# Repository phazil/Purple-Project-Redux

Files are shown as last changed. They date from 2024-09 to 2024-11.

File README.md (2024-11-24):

# Purple Project Redux

A recreation of @TheTrain24's Purple Project seen here:
[Reference Posts](https://github.com/phazil/Purple-Project-Redux/blob/main/Docs/Inspiration%20Posts.md)

This started out as a post graduation project (someone in biology hire me pls) to explore deeper into the hobbies I was already interested in. Did all of the CAD/KiCAD work myself, and also because I missed out on the originals Train posted. Lots was learned here, and documenting it all isn't as fun as making it but I guess it's necessary lol. 

This is my attempt to recreate Train's version, however there are differences. There is no custom wiring terminal pcb, it's not double stacked FR4 for both front/back panel, and there's no usage of low profile OSBMXs. I used a right angle header soldered onto a Basic Breakout Board running GP2040-CE along with a 20-pin wiring harness. There is some soldering involved in this to get the menu panel working however it is sequential and there's only 1 ground line needed. The single panel do not flex at all with the increase inside area of the 3D prints. you would have to try to push down really hard on the center of the panels to even see any sort of flex. Any low profile buttons that fit within a 20mm tall enclosure should work too.

As regards for making and selling, I do not think this is the most efficient way to go about it. The original project I am pretty sure was scrapped due to how expensive FR4 panels end up being. Using laser cut acrylic is probably more efficient for anything of the sorts. Total cost for making 5 of these is about $750 with the materials I chose, so around $160 each is close to breaking even. This does not at all account for the time needed to print parts or build this.

If you need any help or are even thinking about making this please contact me on Discord! I'd be willing to help. @phazil

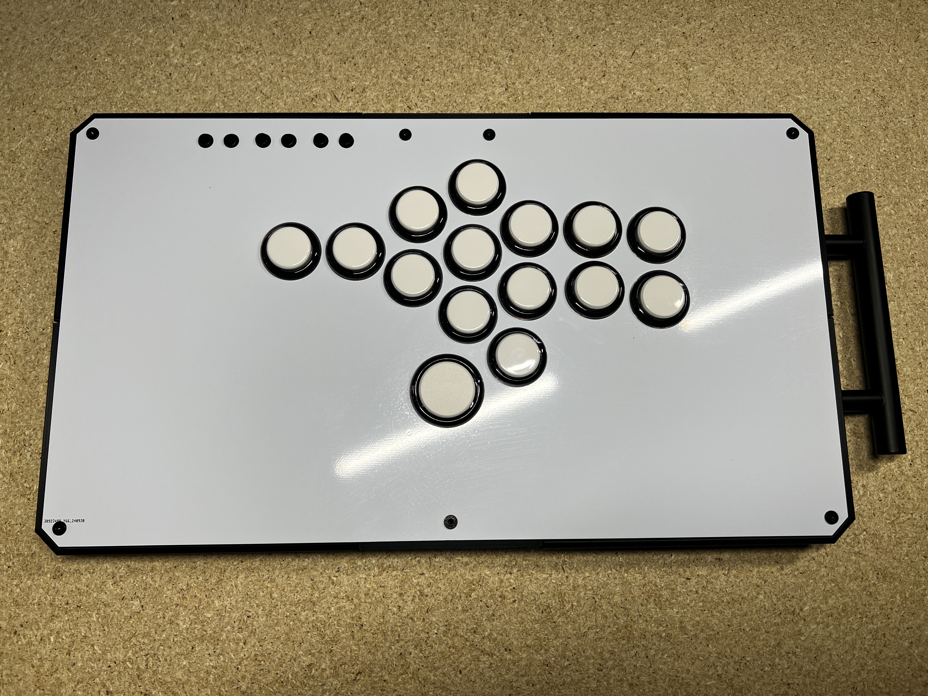
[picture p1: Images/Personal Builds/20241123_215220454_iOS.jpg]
Showcase Test

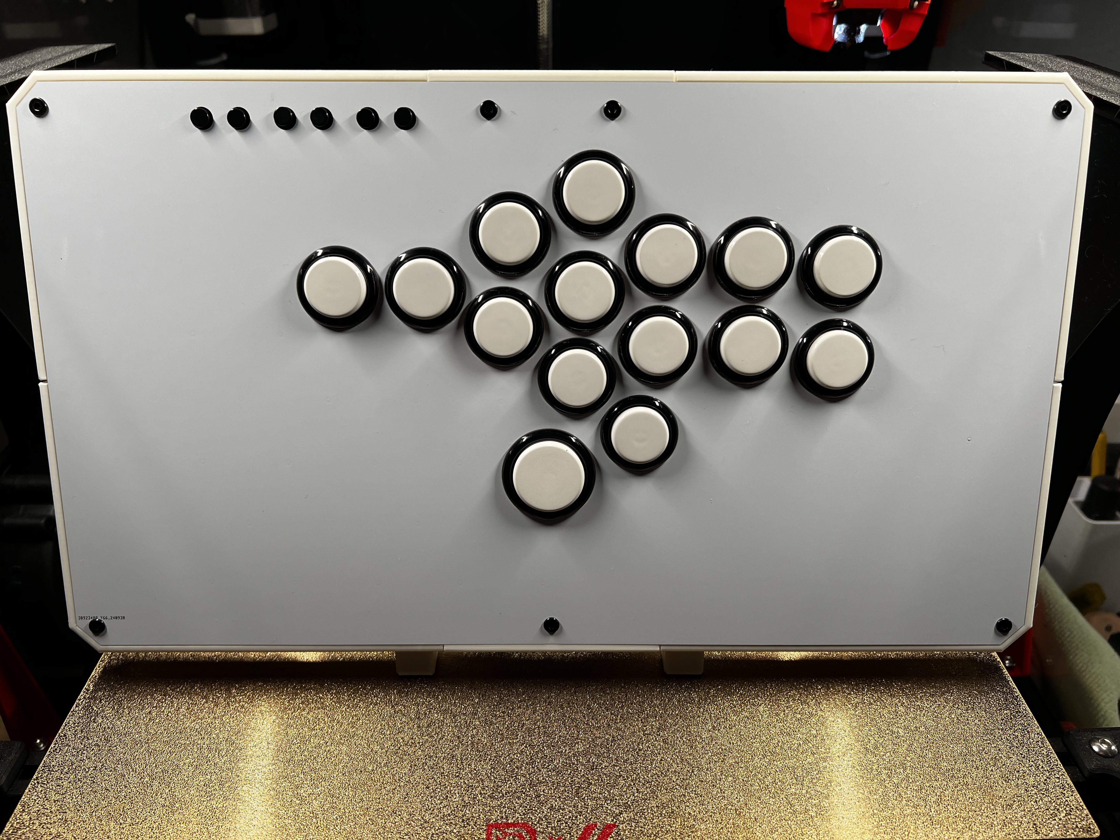
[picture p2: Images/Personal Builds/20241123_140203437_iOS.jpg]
Showcase Test 2


## Repository Directory:
* [Full Readme](https://github.com/phazil/Purple-Project-Redux/blob/main/README.md)
	* [Reference Posts](https://github.com/phazil/Purple-Project-Redux/blob/main/Docs/Inspiration%20Posts.md)
	* [Bill of Materials](https://github.com/phazil/Purple-Project-Redux/blob/main/Docs/Bill%20of%20Materials.md)
   	* [Ordering Panels and PCBs](https://github.com/phazil/Purple-Project-Redux/blob/main/Docs/Ordering%20Guide.md)
 	* [Printing Parts](https://github.com/phazil/Purple-Project-Redux/blob/main/Docs/Printing%20Parts.md)
	* [Rough Assembly Guide](https://github.com/phazil/Purple-Project-Redux/blob/main/Docs/Assembly%20Guide.md)
 	* [Editting Parts](https://github.com/phazil/Purple-Project-Redux/blob/main/Docs/Editting%20Parts.md)

## Features, Details, and To-Dos

### 3 Variations:
- Purple Project Redux: 35.56cm x 20.32cm x 2.32cm (14" x 8" x 0.9")
- **UNTESTED** Acrylic Layer Version: 35.56cm x 20.32cm x 2.47cm (14" x 8" x 0.97")
- Right side carrying handle modifcation available for both (Adds about 1.25" to total length)

### Features:
- Daigo-ish Layout
- Stickless+
- Bottom Rubber Pads
	- Mirrored for both sides
- Right side carrying handle
- PCB top/bottom plate (1.6mm)
- Possible Acrylic Top Plate (3.1mm total thickness, only screw ins work)
- Designed PCB Auxilliary Button Panel

Each designed part can fit in a 250x250x250 volume print bed
- 6 total pieces
	- Top Left
	- Top Right
	- Top Middle (Requires USB-C keystone jack panel mount)
	- Bottom Left
	- Bottom Middle
	- Bottom Right
- Printed in [Voron Spec](https://docs.vorondesign.com/sourcing.html#print-settings) hopefully

### To Do's:
- [x] BOM Page written
- [x] Ordering Page written
- [x] Printing Parts written
- [x] Rough Assembly Guide written
- [x] Editting Parts written
- [ ] Bottom Rubber/Foam pad DXFs

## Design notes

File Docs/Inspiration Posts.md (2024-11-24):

## Repository Directory:
* [Full Readme](https://github.com/phazil/Purple-Project-Redux/blob/main/README.md)
	* [Reference Posts](https://github.com/phazil/Purple-Project-Redux/blob/main/Docs/Inspiration%20Posts.md)
	* [Bill of Materials](https://github.com/phazil/Purple-Project-Redux/blob/main/Docs/Bill%20of%20Materials.md)
   	* [Ordering Panels and PCBs](https://github.com/phazil/Purple-Project-Redux/blob/main/Docs/Ordering%20Guide.md)
 	* [Printing Parts](https://github.com/phazil/Purple-Project-Redux/blob/main/Docs/Printing%20Parts.md)
	* [Rough Assembly Guide](https://github.com/phazil/Purple-Project-Redux/blob/main/Docs/Assembly%20Guide.md)
 	* [Editting Parts](https://github.com/phazil/Purple-Project-Redux/blob/main/Docs/Editting%20Parts.md)

## These are the original posts that I used as a reference for this project

[Detailed Pictures Stored Here](https://github.com/phazil/Purple-Project-Redux/tree/main/Images/OpenStickCommunity%20Posts/2)

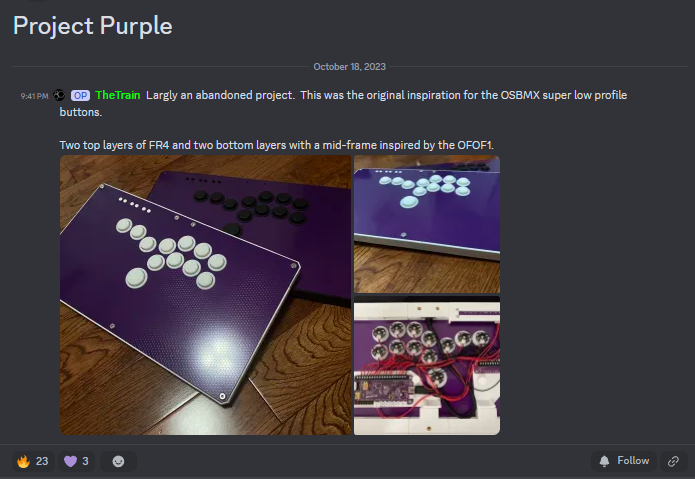
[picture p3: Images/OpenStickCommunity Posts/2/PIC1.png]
Reference Post 1


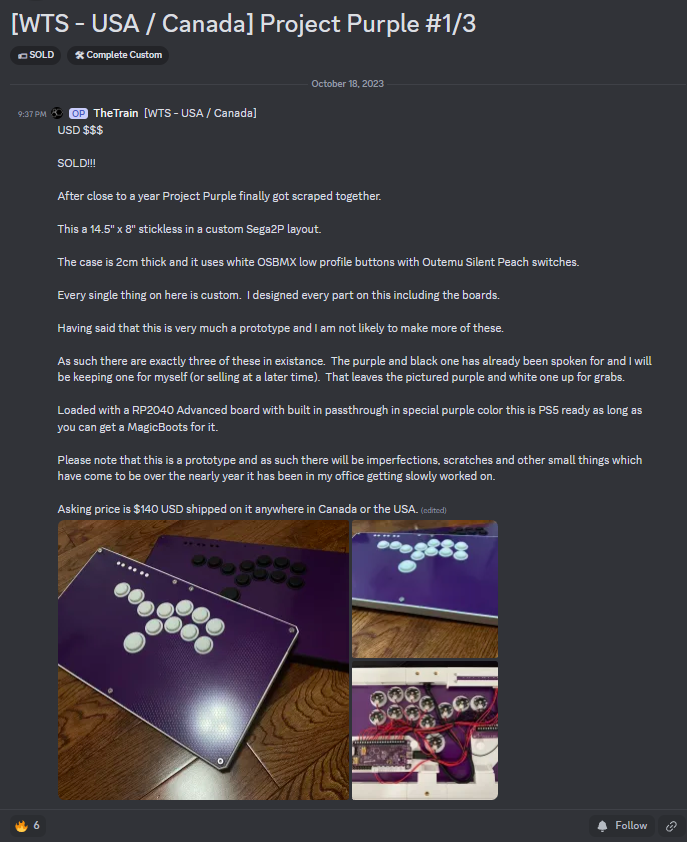
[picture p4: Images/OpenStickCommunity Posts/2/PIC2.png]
Reference Post 2


[Detailed Pictures of This Post Here](https://github.com/phazil/Purple-Project-Redux/tree/main/Images/OpenStickCommunity%20Posts/2)

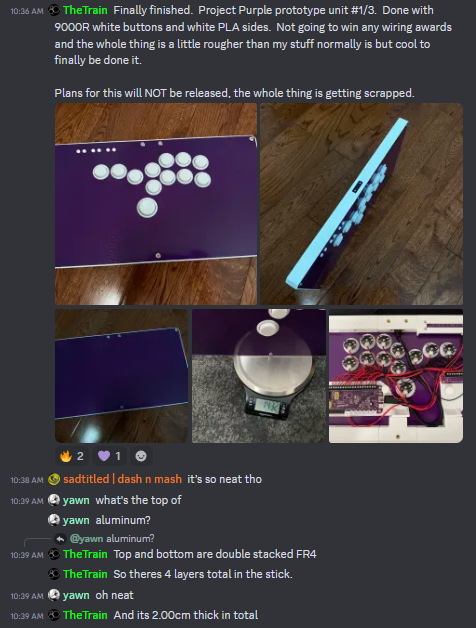
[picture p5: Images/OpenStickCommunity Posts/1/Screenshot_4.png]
Reference Post 3


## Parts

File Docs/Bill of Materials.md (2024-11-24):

## Repository Directory:
* [Full Readme](https://github.com/phazil/Purple-Project-Redux/blob/main/README.md)
	* [Reference Posts](https://github.com/phazil/Purple-Project-Redux/blob/main/Docs/Inspiration%20Posts.md)
	* [Bill of Materials](https://github.com/phazil/Purple-Project-Redux/blob/main/Docs/Bill%20of%20Materials.md)
   	* [Ordering Panels and PCBs](https://github.com/phazil/Purple-Project-Redux/blob/main/Docs/Ordering%20Guide.md)
 	* [Printing Parts](https://github.com/phazil/Purple-Project-Redux/blob/main/Docs/Printing%20Parts.md)
	* [Rough Assembly Guide](https://github.com/phazil/Purple-Project-Redux/blob/main/Docs/Assembly%20Guide.md)
 	* [Editting Parts](https://github.com/phazil/Purple-Project-Redux/blob/main/Docs/Editting%20Parts.md)

## Bill of Materials:

There is a mix of Aliexpress links and Amazon links used here. There is no affiliate/metadata tracking on these links.

- [Overture PLA works w/ Bambulabs AMS](https://www.amazon.com/gp/product/B082W64GTZ)
- [Voron Spec Heatset Inserts M3x5x4](https://www.amazon.com/gp/product/B0CDH36ZMX)
- Three different version of USB-C Keystone Jack inserts, pick whatever works
  - [Black USB-C Keystone Jack](https://www.amazon.com/gp/product/B0CP753PCP)
  - [White USB-C Keystone Jack](https://www.amazon.com/gp/product/B078495TVK)
  - [Use this one if not using Stickless+ Panels](https://www.amazon.com/gp/product/B08GSQ13C8)
- [Handle Used + Screws](https://www.amazon.com/gp/product/B085ZRBTPY)
- M3x4 or M3x6
  - [Black Screws](https://www.aliexpress.us/item/3256804883804669.html)
  - [Silver Screws](https://www.aliexpress.us/item/3256802038301655.html)
- [Low Profile SiTongs](https://www.aliexpress.us/item/3256807199829923.html)
- [6x6x7/8 A56 Momentary Pushbutton](https://www.ebay.co.uk/itm/233216080460) If you didn't get the Menu Panel assembled with push buttons.
- [Menu Panel Caps](https://www.aliexpress.us/item/3256804815046475.html)

- Some kind of Advanced/Basic Breakout Boards running GP2040-CE
  - [Right Angle Header if you're interested in using a wiring harness in the build](https://www.amazon.com/gp/product/B00W8TSWXS)
 
## Total Counts:

- Button Panel
  - Optional Acrylic Layer
- Back Panel
- 20 M3x4/6 screws
  - 14 screws for the panels
  - 6 for holding down PCBs inside
- 14 M3x5x4 Heatset Inserts
- 1 USB-C Keystone Jack
- 1 Advanced/Basic Breakout Board
- 1 Menu Panel PCB
- 6 6x6x7/8 Momentary Push Buttons
- 6 A56 Button Caps
- Low Profile Buttons (SiTongs/Monkey BuTTs etc.)
  - 24mms Buttons
    - 14 for Stickless+
    - 13 for Daigo-ish
    - 11 for Standard Leverless
  - 1 30mm

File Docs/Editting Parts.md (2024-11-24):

## Repository Directory:
* [Full Readme](https://github.com/phazil/Purple-Project-Redux/blob/main/README.md)
	* [Reference Posts](https://github.com/phazil/Purple-Project-Redux/blob/main/Docs/Inspiration%20Posts.md)
	* [Bill of Materials](https://github.com/phazil/Purple-Project-Redux/blob/main/Docs/Bill%20of%20Materials.md)
   	* [Ordering Panels and PCBs](https://github.com/phazil/Purple-Project-Redux/blob/main/Docs/Ordering%20Guide.md)
 	* [Printing Parts](https://github.com/phazil/Purple-Project-Redux/blob/main/Docs/Printing%20Parts.md)
	* [Rough Assembly Guide](https://github.com/phazil/Purple-Project-Redux/blob/main/Docs/Assembly%20Guide.md)
 	* [Editting Parts](https://github.com/phazil/Purple-Project-Redux/blob/main/Docs/Editting%20Parts.md)

## Editting Parts

Within the [Source Files Folder](https://github.com/phazil/Purple-Project-Redux/tree/main/Source%20Files) everything is accessible and changeable.

DXFs, STEPs, and PCB files are all available.

They were created in Fusion 360 and KiCAD 8.0.

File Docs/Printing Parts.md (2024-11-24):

## Repository Directory:
* [Full Readme](https://github.com/phazil/Purple-Project-Redux/blob/main/README.md)
	* [Reference Posts](https://github.com/phazil/Purple-Project-Redux/blob/main/Docs/Inspiration%20Posts.md)
	* [Bill of Materials](https://github.com/phazil/Purple-Project-Redux/blob/main/Docs/Bill%20of%20Materials.md)
   	* [Ordering Panels and PCBs](https://github.com/phazil/Purple-Project-Redux/blob/main/Docs/Ordering%20Guide.md)
 	* [Printing Parts](https://github.com/phazil/Purple-Project-Redux/blob/main/Docs/Printing%20Parts.md)
	* [Rough Assembly Guide](https://github.com/phazil/Purple-Project-Redux/blob/main/Docs/Assembly%20Guide.md)
 	* [Editting Parts](https://github.com/phazil/Purple-Project-Redux/blob/main/Docs/Editting%20Parts.md)

## Printing Parts:
The [STL folder](https://github.com/phazil/Purple-Project-Redux/tree/main/For%20Makers/STLs) is organized for you to print the base version then expand onto any variations you're interested in.

***The Stickless+ Version Panels has the USB-C Keystone Passthrough collide with the button housings, an alternative version is provided where the USB-C port is shifted over to avoid colliding if you're not interested in clipping the port down.***

Each designed part can fit in a **250x250x250 volume** print bed

Total print time is about **10 hours** and around **11 with supports**.

Total filament used is about **300 grams**. All parts were designed with PLA usage in mind, you would have to account for ABS/ASA shrinkage on your own if you're interested in that material. PETG is also useable too. PLA users please remember to take care of storing this controller in 90*F weather as it may warp in direct sunlight.

All parts are already orientated in printing position. The PCB piece can use **tree supports on the build plate only**. 
- 6 total pieces
	- Top Left
	- Top Right
	- Top Middle (Requires USB-C keystone jack panel mount)
	- Bottom Left
	- Bottom Middle
	- Bottom Right

These settings help give a rigid feeling when putting the build together. Although 3 walls/top layers will also work with a 20% infill density
- Printed in [Voron Spec](https://docs.vorondesign.com/sourcing.html#print-settings) hopefully
  - Layer height: 0.2mm
  - Extrusion width: 0.4mm, forced
  - Infill percentage: 40%
  - Infill type: grid, gyroid, honeycomb, triangle, or cubic
  - Wall count: 4
  - Solid top/bottom layers: 5
  - Supports: NONE

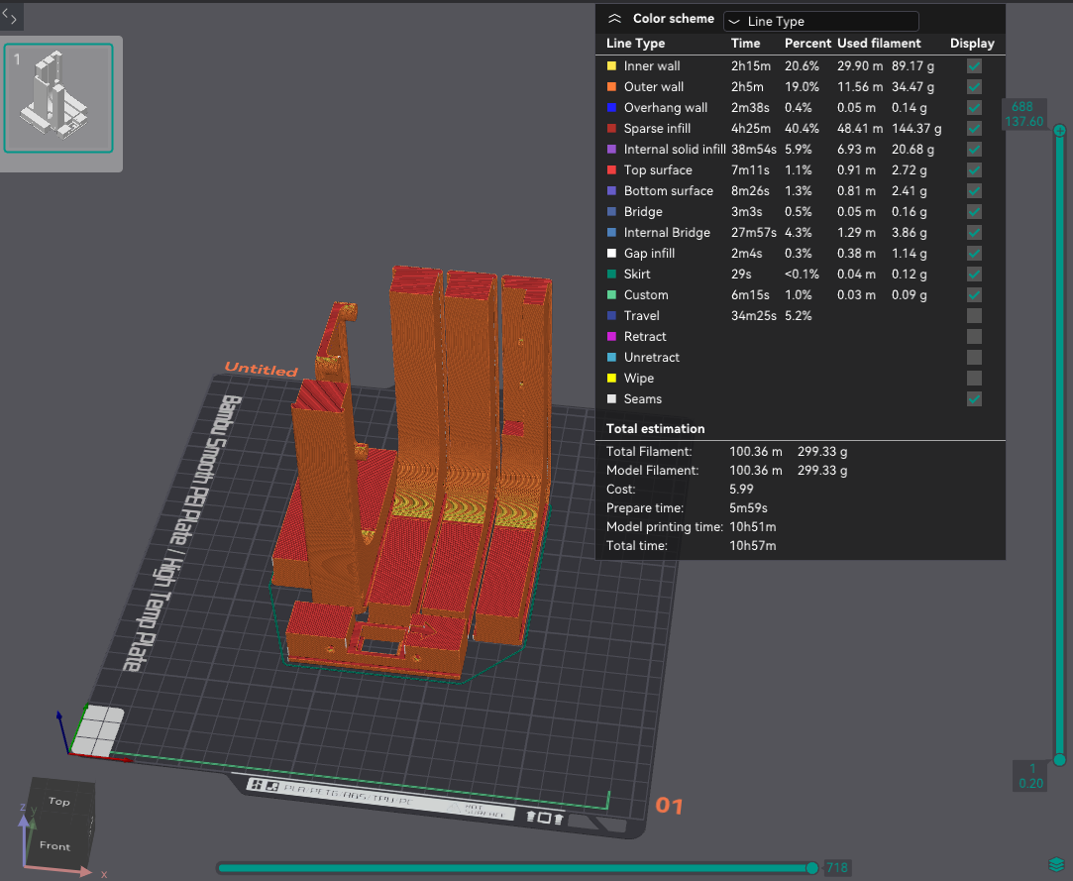
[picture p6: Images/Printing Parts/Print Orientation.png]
Print Orientation 1

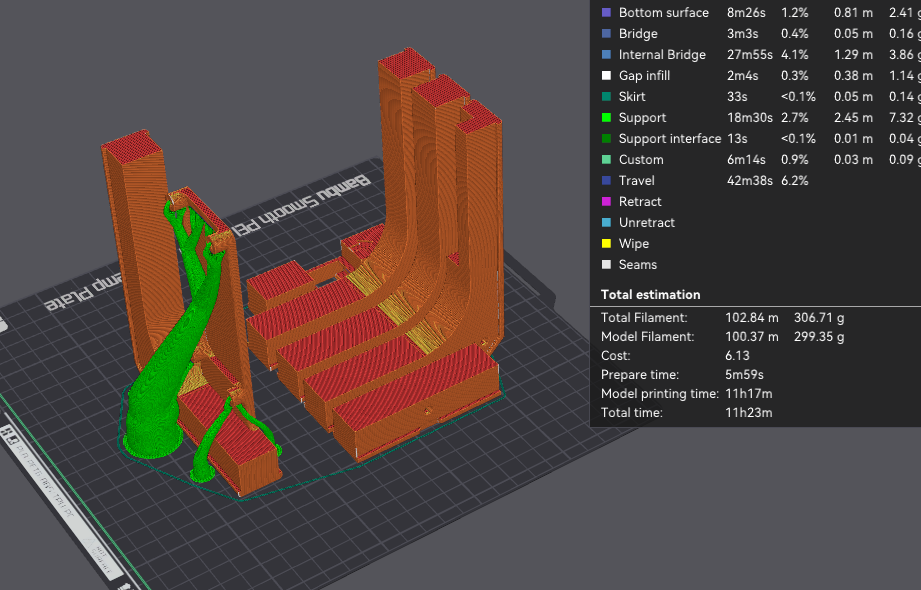
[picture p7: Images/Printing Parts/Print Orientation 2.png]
Print Orientation 2


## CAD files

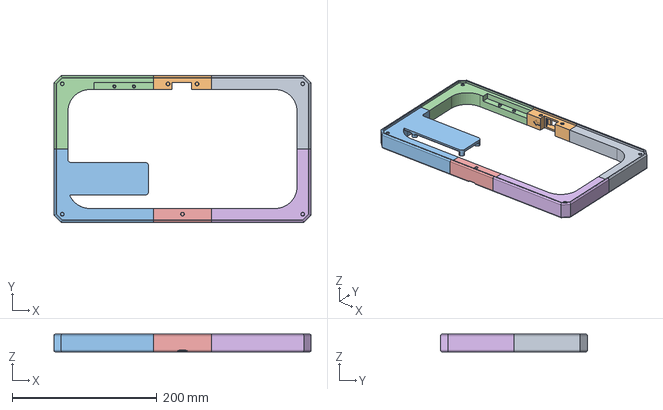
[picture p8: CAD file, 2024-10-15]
Source Files/STEP Files/Orignal + Acrylic/Full Body Acrylic.step
355.6 x 203.2 x 24.7 mm

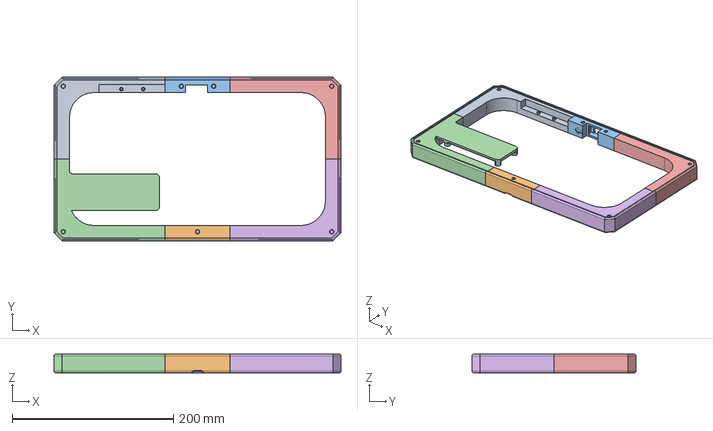
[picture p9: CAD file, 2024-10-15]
Source Files/STEP Files/Original/Full Body No Acrylic.step
355.6 x 203.2 x 23.2 mm

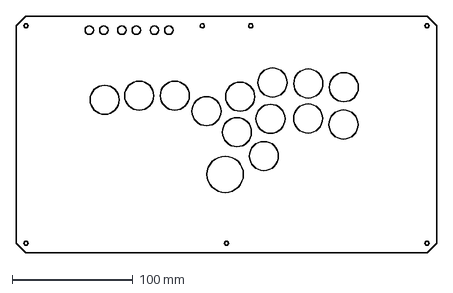
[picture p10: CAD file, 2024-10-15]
For Makers/Panel DXFs/Daigo-ish.dxf
348.6 x 196.2 mm

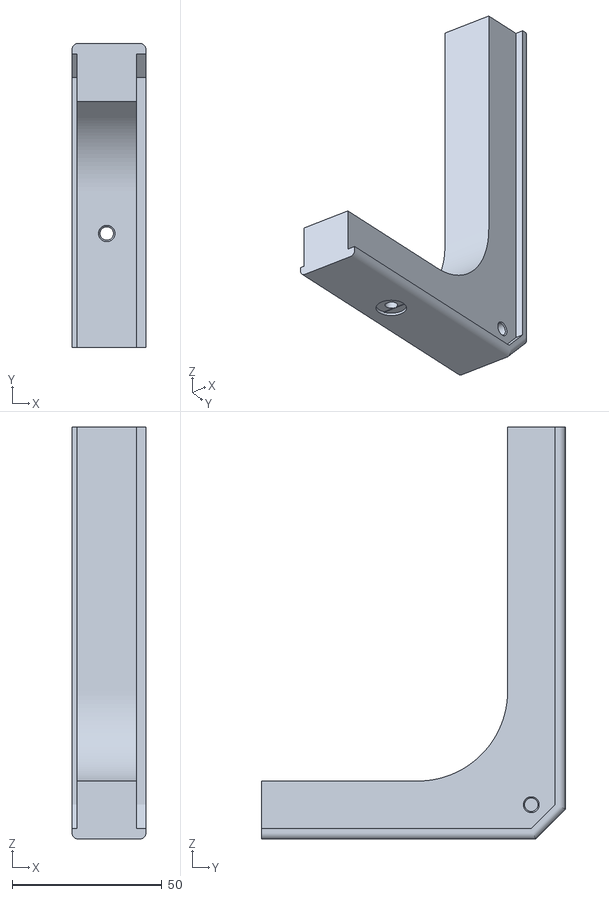
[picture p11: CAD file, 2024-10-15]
For Makers/STLs/Original + Acrylic/Right Side Handles/Top Right Acrylic Handle.stl
24.7 x 101.6 x 137.6

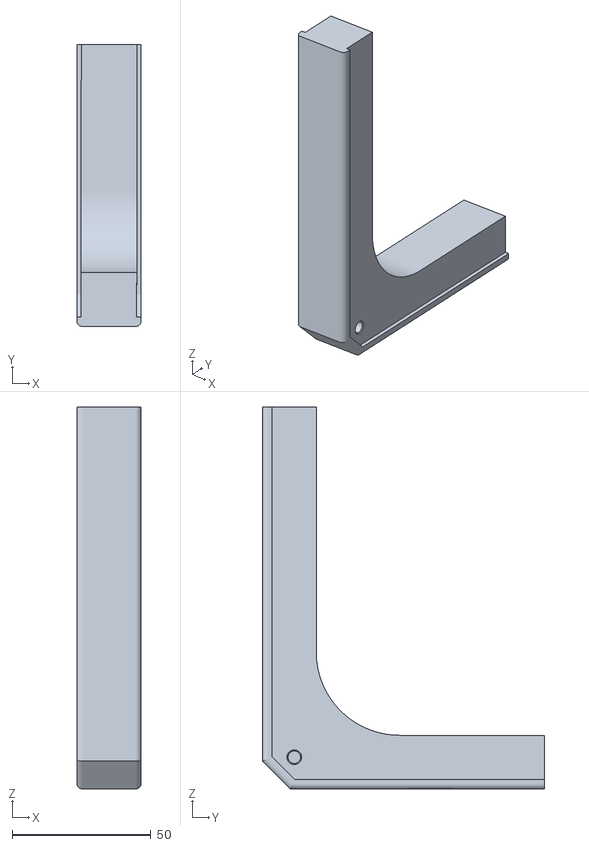
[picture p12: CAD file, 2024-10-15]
For Makers/STLs/Original/Bottom Right No Handle.stl
23.2 x 101.6 x 137.6

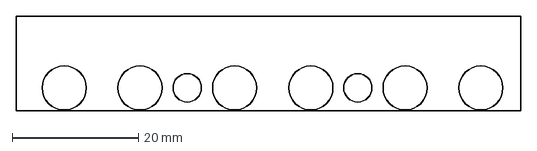
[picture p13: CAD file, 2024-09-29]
Source Files/KiCAD Files/MenuPanel/MenuPanelDXFforKiCAD.dxf
80.0 x 15.0 mm

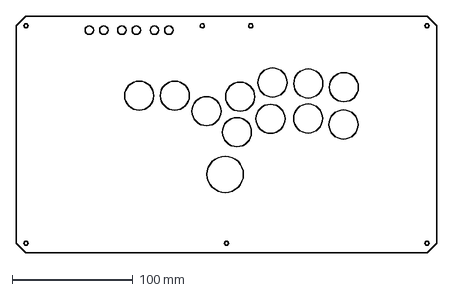
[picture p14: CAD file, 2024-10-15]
Source Files/Panel DXFs/Leverless.dxf
348.6 x 196.2 mm

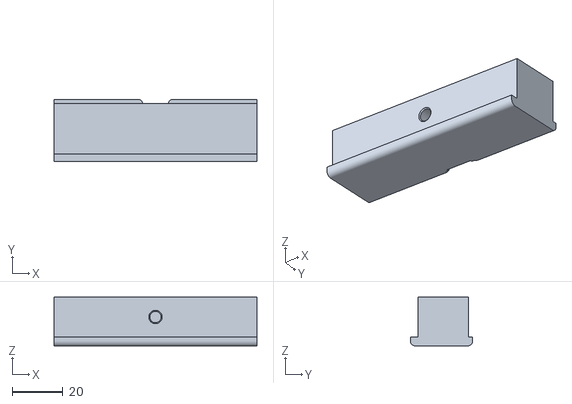
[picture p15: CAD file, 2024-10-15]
For Makers/STLs/Original + Acrylic/Bottom Middle Acrylic.stl
80.3 x 24.7 x 19.4

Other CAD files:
For Makers/STLs/Original + Acrylic/SticklessPLUS STLs/Top Right StickPLUS No Handle Acrylic.stl
For Makers/STLs/Original + Acrylic/Top Left Acrylic.stl
For Makers/STLs/Original/Right Side Handle STLs/Bottom Right Handle.stl
For Makers/STLs/Original/SticklessPLUS STLs/Top Right StickPLUS No Handle.stl
Source Files/STEP Files/Original/Right Side Handle/Bottom Right Handle.step
Source Files/STEP Files/Original/SticklessPLUS STEP/Top Right StickPLUS Handle.step
Source Files/STEP Files/Original/Top Right.step
Source Files/STEP Files/Orignal + Acrylic/Right Side Handle/Bottom Right Handle Acrylic.step
Source Files/STEP Files/Orignal + Acrylic/SticklessPLUS STEP/Top Right StickPLUS No Handle Acrylic.step
For Makers/Panel DXFs/Back Panel.dxf
For Makers/Panel DXFs/SticklessPLUS.dxf
For Makers/STLs/Original + Acrylic/Bottom Left Acrylic.stl
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

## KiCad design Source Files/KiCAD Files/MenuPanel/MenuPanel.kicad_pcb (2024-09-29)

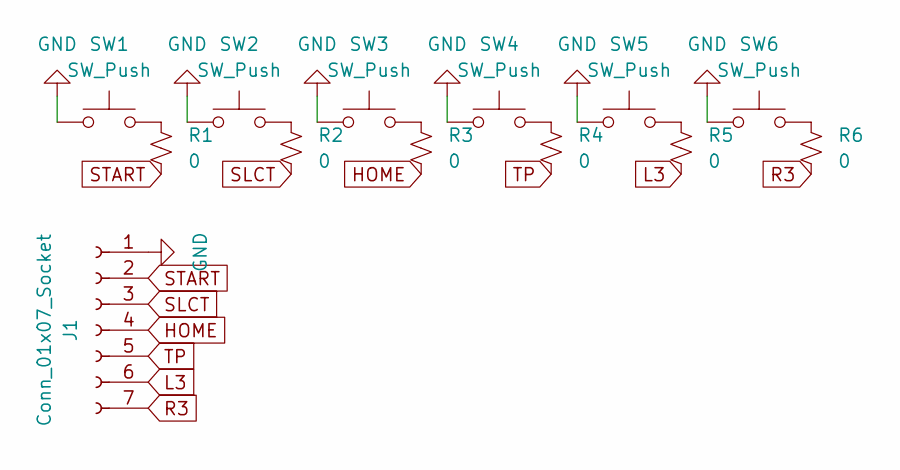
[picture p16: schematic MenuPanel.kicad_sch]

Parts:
J1: Conn_01x07_Socket; PinSocket_1x07_P2.54mm_Vertical
R1, R2, R3, R4, R5, R6: 0; R_0805_2012Metric_Pad1.20x1.40mm_HandSolder
SW1, SW2, SW3, SW4, SW5, SW6: SW_Push; SW_PUSH_6mm_H4.3mm

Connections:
GND: J1.1, SW1.1, SW2.1, SW3.1, SW4.1, SW5.1, SW6.1
HOME: J1.4, R3.2
L3: J1.6, R5.2
unnamed: R1.1, SW1.2
unnamed: R2.1, SW2.2
unnamed: R3.1, SW3.2
unnamed: R4.1, SW4.2
unnamed: R5.1, SW5.2
unnamed: R6.1, SW6.2
R3: J1.7, R6.2
SLCT: J1.3, R2.2
START: J1.2, R1.2
TP: J1.5, R4.2

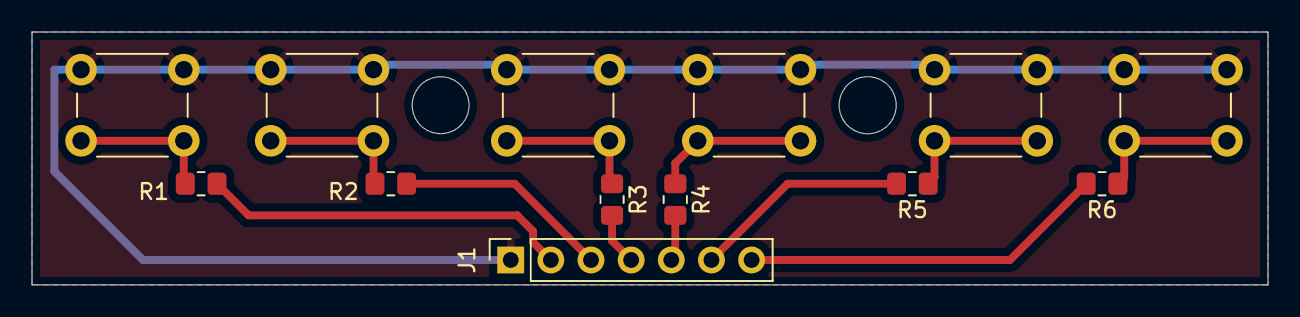
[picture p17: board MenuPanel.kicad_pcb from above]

Board: 2 copper layers, 78.2 x 16.0 mm, 13 parts (0 on the bottom side), 13 nets.

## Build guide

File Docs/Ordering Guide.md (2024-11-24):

## Repository Directory:
* [Full Readme](https://github.com/phazil/Purple-Project-Redux/blob/main/README.md)
	* [Reference Posts](https://github.com/phazil/Purple-Project-Redux/blob/main/Docs/Inspiration%20Posts.md)
	* [Bill of Materials](https://github.com/phazil/Purple-Project-Redux/blob/main/Docs/Bill%20of%20Materials.md)
   	* [Ordering Panels and PCBs](https://github.com/phazil/Purple-Project-Redux/blob/main/Docs/Ordering%20Guide.md)
 	* [Printing Parts](https://github.com/phazil/Purple-Project-Redux/blob/main/Docs/Printing%20Parts.md)
	* [Rough Assembly Guide](https://github.com/phazil/Purple-Project-Redux/blob/main/Docs/Assembly%20Guide.md)
 	* [Editting Parts](https://github.com/phazil/Purple-Project-Redux/blob/main/Docs/Editting%20Parts.md)

## Ordering Guide

I used JLCPCB for these. 1.6mm PCB thickness. Remove Order Number. Pick your panel color and silkscreen color. Obviously white silkscreen on black panels and black on white panels if you want it like that. The back panel is reversible too if you're not interested in the logos. Pick whatever surface finish is cheapest for you or whatever you favor.

JLC QC/QA might flag you asking if there's any grounding/metal on the panels. Just accept the risks and they should come out fine.

Within the [Panel Production Files](https://github.com/phazil/Purple-Project-Redux/tree/main/For%20Makers/Panel%20Production%20Files) you need to pick a front panel then add on the back panels.

As for the MenuPanel you will need assembly as I did include 0 ohm resistors just in case they were needed.

The Zip file included has the production files/BOM/designators/locations, you can choose to have JLCPCB install the momentary push buttons or you can do them yourself. 1.6mm and whatever color you want if that matters.

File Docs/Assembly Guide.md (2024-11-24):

## Repository Directory:
* [Full Readme](https://github.com/phazil/Purple-Project-Redux/blob/main/README.md)
	* [Reference Posts](https://github.com/phazil/Purple-Project-Redux/blob/main/Docs/Inspiration%20Posts.md)
	* [Bill of Materials](https://github.com/phazil/Purple-Project-Redux/blob/main/Docs/Bill%20of%20Materials.md)
   	* [Ordering Panels and PCBs](https://github.com/phazil/Purple-Project-Redux/blob/main/Docs/Ordering%20Guide.md)
 	* [Printing Parts](https://github.com/phazil/Purple-Project-Redux/blob/main/Docs/Printing%20Parts.md)
	* [Rough Assembly Guide](https://github.com/phazil/Purple-Project-Redux/blob/main/Docs/Assembly%20Guide.md)
 	* [Editting Parts](https://github.com/phazil/Purple-Project-Redux/blob/main/Docs/Editting%20Parts.md)

## Assembly Guide:

This is going to be really rough as it's a pretty simple build but there is an order I found to be pretty efficient. I am assuming you're pretty crafty/mechanically inclined to be able to wield a soldering iron especially if you're able to 3D print these parts.

## Build:

Heatset Inserts first
  > How even and straight you press them in is pretty important for how the panels sit.

Insert Buttons into front panel

Insert USB-C Keystone Jack into Top Middle piece, there is an arrow to orientate you to which way. It only goes in one way.

Screw 4 or 5 of the 6 pieces onto the front panel, you would have to hold off on the Top Left piece so you can handle the PCBs.

Screw in the Menu Panel PCB, should take 2 M3s directly into the 3D print

Screw in Main PCB (ABB or BBB) directly into the 3D print

Start wiring your action and movement buttons
  > Take your time with this as how neat you handle it saves you so much space

Solder your Menu Panel the square through hole is ground, and if you're using a wiring harness you can snip/strip then solder it into the hole. You can pick the order of what you want your buttons to be. I generally did Start/Select/Home/TP/L3/R3. From Left to Right after the ground.

OPTIONAL Solder your/plug in your extra face buttons if you're using Stickless+ or Daigo-ish layouts

After you're done wiring you can screw Top Left/Bottom Left onto the front panel only reason why we didn't do this earlier as it was easier to manipulate these pieces to access.

Close it up and you should be good, if you mess up there is a little indent on Bottom Middle to let you open it up again

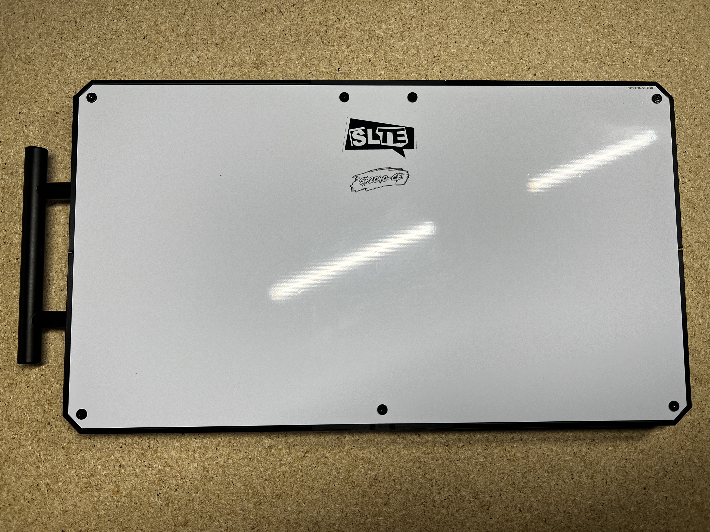
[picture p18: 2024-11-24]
Images/Personal Builds/20241123_215338252_iOS.jpg

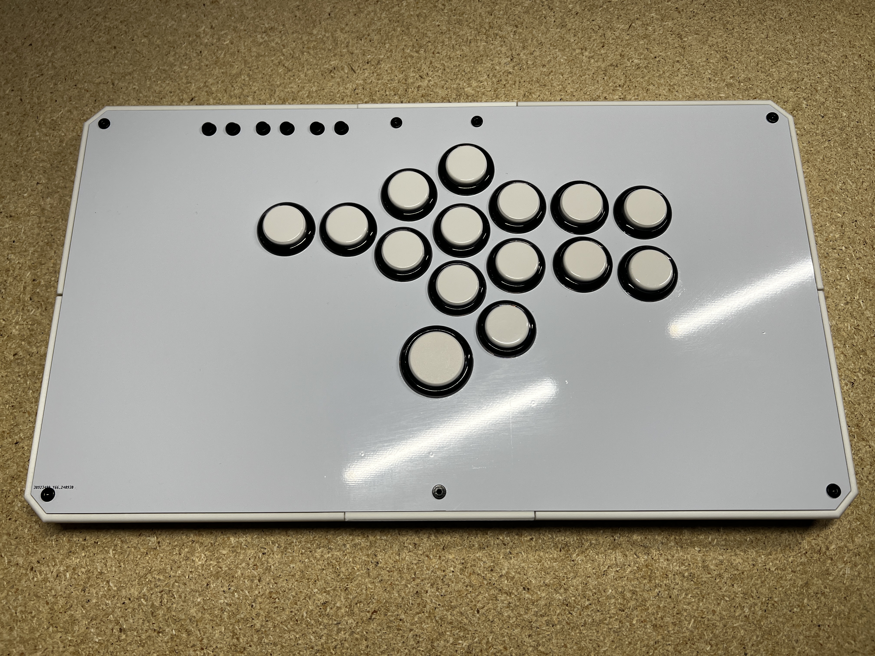
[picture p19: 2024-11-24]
Images/Personal Builds/20241123_215536130_iOS.jpg

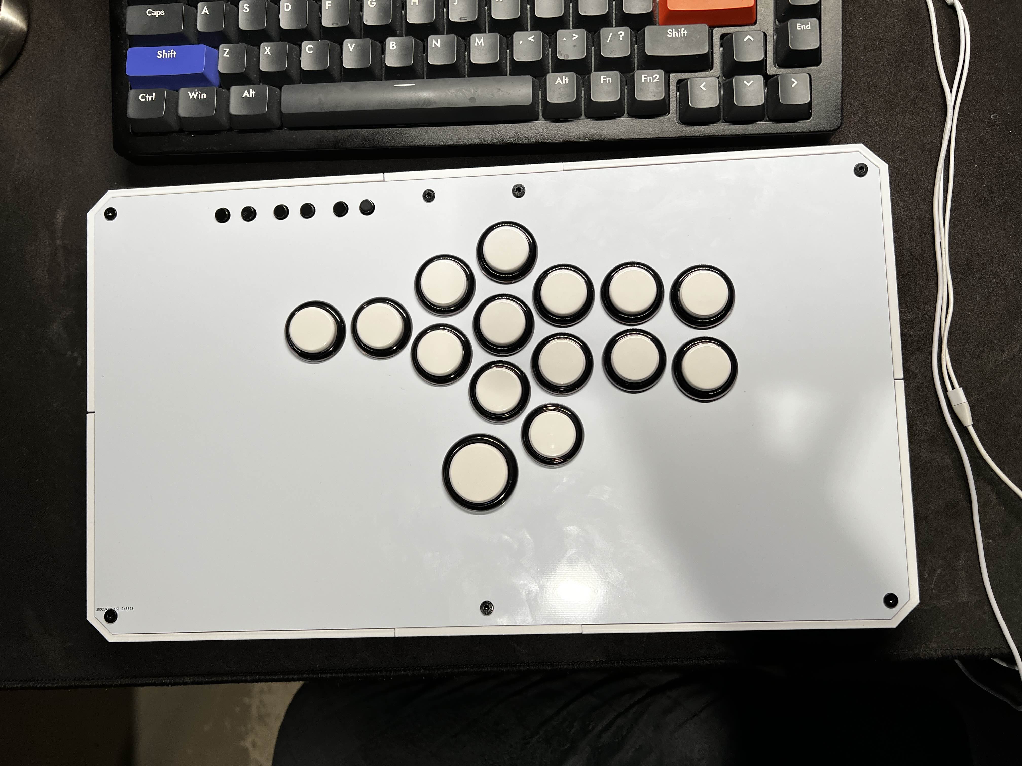
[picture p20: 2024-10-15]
Images/Personal Builds/IMG_2287.jpg

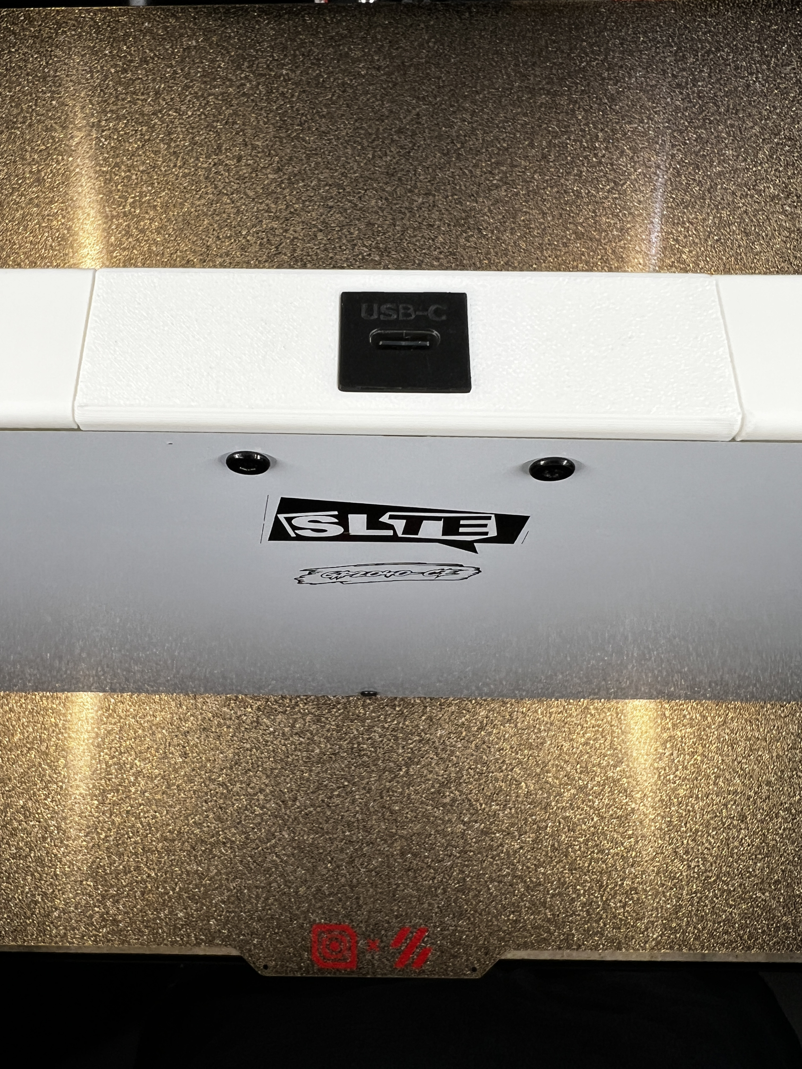
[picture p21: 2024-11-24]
Images/Personal Builds/20241123_140255928_iOS.jpg

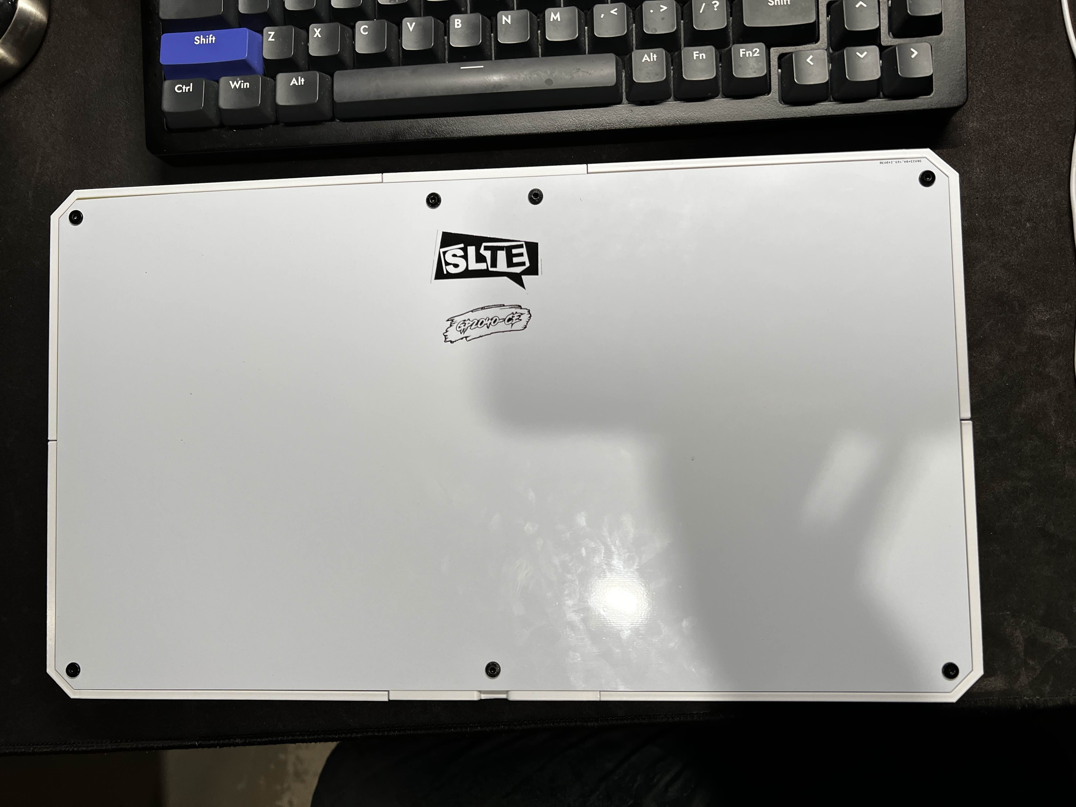
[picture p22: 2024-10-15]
Images/Personal Builds/IMG_2288.jpg

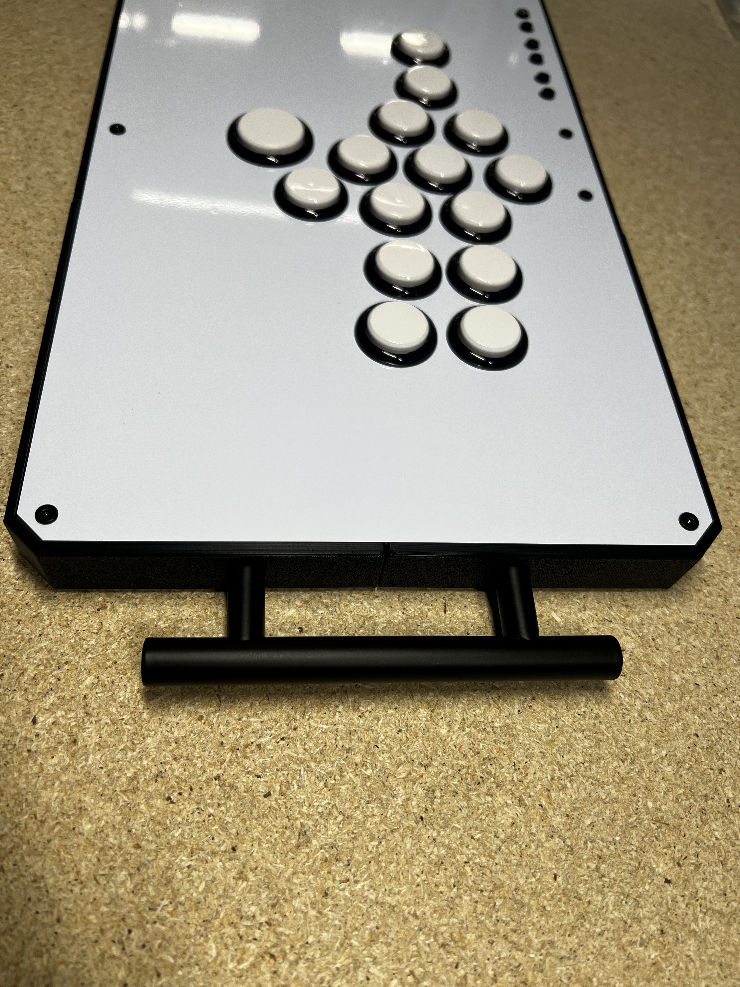
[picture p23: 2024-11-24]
Images/Personal Builds/20241123_215231068_iOS.jpg

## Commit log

2024-11-23 Update Printing Parts.md
2024-11-23 Update Bill of Materials.md
2024-11-24 Update Assembly Guide.md
